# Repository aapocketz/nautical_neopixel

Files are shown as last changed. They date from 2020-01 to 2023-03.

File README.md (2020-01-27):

# Nautical Neopixel Arduino project

This arduino sketch is designed to be programmed into a framed nautical chart in order to light up the buoys, lighthouses, channel markers and other lighted nautical aids to navigation found on a NOAA nautical chart. Each light has a color and flashing/timing characteristic which can be simulated. This would make an interesting art display or a project for someone learning or experimenting with microcontrollers.

See the comments in the sketch for more information on implementation.

You can simulate the operation of the arduino and LEDs on Tinkercad Circuit simulator https://www.tinkercad.com/things/gWAsxpgxWYh.

The chart I printed required over a hundred lighted aids to navigation, some that even printed out in a large format (20x30in) some lateral buoys/marks are spaced closely. I wanted to light them all, so decided to use 1mm fiber optics. This solved the problem with spacing - Neopixels are very small, but even 5050 LEDs are 5mm wide. Since most of the buoys in a given chart will have the same color and timing, you can also multiplex map several fibers fed from a single LED, and even the chart I printed with hundred of lights only required fewer than 20 unique LEDs. By using fewer LEDs and being smarter about power you could also make this project battery powered. 

# SCAD 3D print
To mate the optical fiber to the LEDs, I designed a coupler that makes it easy to mate the fiber to individual LEDs. This SCAD is customizable and can be accessed directly using thingiverse customizer https://www.thingiverse.com/thing:3881790. 

# parts and tools required and project assembly

1. Frame a nautical chart. Find a nautical chart, and a print service and frame style that will work for you. I went with samsclub photo as they have "standout" prints 20x30in for ~$80. Standout prints are a good option as it is a nice hard surface to drill into to mount the LEDs and have a nice deep frame to hide electronics. To print a nautical chart you can get PDF charts for free from NOAA https://nauticalcharts.noaa.gov/. Keep in mind the aspect ratio is varied with each chart, and you will need to either find a print service that can handle custom sizes or crop/trim the image to fit. To match the modern black standout frame and modern look of LEDs I inverted the image which created an image that was darker and I think goes better with the frame and nautical lights against a dark background at night.\
\
For example this is the image I had printed from chart 12270 (warning large image):\
\
Note: I am not sure I would recommend the samsclub standouts, as they have a hard backing and it glued up with styrofoam inside which I didn't realize. To get this project to work I had to cut the backing off and carve out the styrofoam to mount the electronics. It would have been easier with standout frame that had a hollow backing with no solid foam layer. Box mount or canvas mount frames that are hollow in the back may be a better option. 

2. Program the Arduino. I used an Andruino nano board clone from Amazon (a pack of 3 was about $13). https://www.amazon.com/ELEGOO-Arduino-ATmega328P-Without-Compatible/dp/B0713XK923. Figure out the different light sequences you will need for your chart and edit the arduino sketch to include the number of unique LEDs and timing needed.  
*ProTip: Note each nautical light should be clearly printed on the NOAA chart and with a sequence described in chart 1. Also the coast guard provides a list of all the lights in a chart for regions which is a great reference https://www.navcen.uscg.gov/?pageName=lightLists. It helps to put all of them in a spreadsheet and sort by unique to find out how many different unique LEDs you will need. If you have a bunch of the same sequenced lights (ex. flashing green 4s), you may want to have multiple LEDs allocated with them. I wouldn't put more than maybe 10 1mm fibers in a single bundle for each LED (note this is an example of an interesting 2D packing problem https://en.wikipedia.org/wiki/Circle_packing_in_a_circle).*

3. Connect the Arduino to the LED strip to test functionality. I used a cheap ws2812b 144/1M 5050 led strip I found on ebay for ~$12. Trim to the number of LEDs your chart requires. I soldered wire directly to the arduino through holes from the LED strip to finalize the attachment.

4. 3D print the coupler from thingiverse. The LED strip should mount easily in the assembly with channels for optical fiber to each LED. Figure out where you will mount the LEDs behind your frame.

5. Drill holes for each fiber optic to poke through the print. I used a 1mm drill bit attached to a dremel. If you don't have a dremel you could use a small hand drill like a pin vise, which are very cheap. 

6. Mount the optical fiber. Push the fiber through each hole in the print, trimming the end with a flush cutter/wire cutter. To prevent the end from pulling through the print and to spread the light a bit, tap the end of the soldering iron to the end of the fiber, the plastic will mushroom out a bit preventing it from pulling through. Make sure you leave enough fiber length to reach the place where you are mounting the LEDs in the frame.
50m of 1mm fiber optics is about $8 on amazon https://smile.amazon.com/gp/product/B07W979RH3/. 

7. route the fiber optics to the LEDs and attach them to the coupler. I recommend only mounting fiber and routing for a single LED color at a time, so for instance all Flashing Red 2.5s should be pushed through and attached before going on to the next color/timing. To attach to the coupler I recommend clear gorilla glue ($8 for a large bottle https://smile.amazon.com/Gorilla-Clear-Glue-ounce-Bottle/dp/B074J7XQZT) as it dries really clear to not block light. I don't recommend hot glue as you can easily melt the fiber optics! The only downside of the Gorilla glue is it takes time to set, so I recommend gluing up one LED at a time and letting it set before working on the next LED.

8. Mount the power cable. I powered the Arduino using a USB panel mount connector. USB cables are cheap and it allows the program to be reprogrammable after framing. You could also power the project with a barrel connector and a cheap 5v supply, or even use batteries. USB type B to USB mini panel mount connector is about $9 https://www.amazon.com/gp/product/B07PJYNTKS/. Note the panel mount I ordered didn't come with screws, but I had some spare screws that worked (I think size M3).

9. Cover the backing. This is optional, but with loose fiber everywhere it helps encapsulate everything. I glued a black plastic corregated board to the back ($4 at https://www.michaels.com/plastic-corrugated-board-by-creatology/M10567770.html).

## results

video of chart LEDs flashing: https://youtu.be/PLgCkBzhD6o  
video of 3D printed LED coupler: https://www.youtube.com/watch?v=q0YkyLGdePY

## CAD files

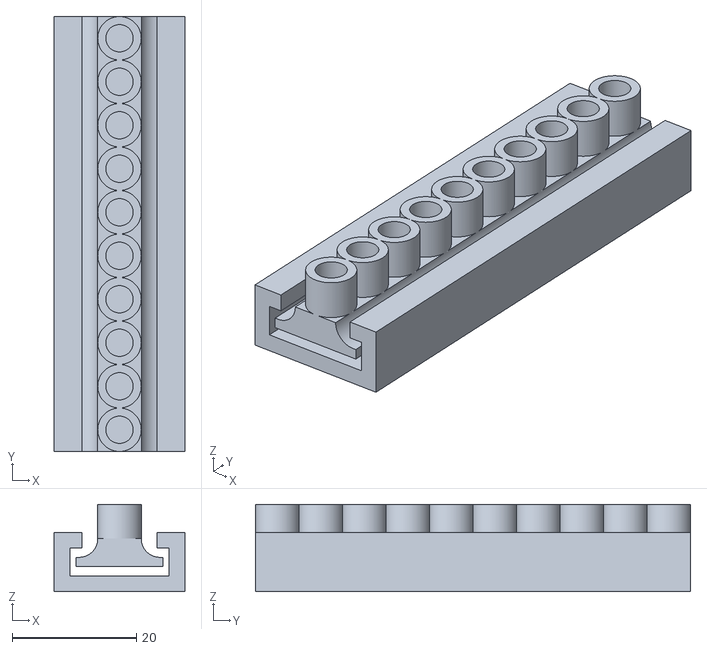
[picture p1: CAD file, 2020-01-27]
neopixel_fiber_adapter.stl
21.0 x 70.0 x 14.0

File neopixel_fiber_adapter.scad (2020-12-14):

/* [Global] */

// Which one would you like to see?
part = "both"; // [top:Top Only,base:Base Only,both:Top and Base]

/* [Top] */

// number of holes for LEDs
led_count = 10;
// length of the tube for fiber optics
tube_height = 10;
// width of the base (wings at bottom)
width = 14.0;
// radius of the chamfer to the wings. Larger number is more gradual chamfer.
chamfer_radius = 3.0;
// radius of the fillet of the base. This is mainly there to make it easier to print
fillet_radius = 1.0;
// the height fo the base (wings) on the side. Chamfer radius + wing height must be less than the tube_height
wing_height = 1.5;

// LED size (ws2812b according to datasheet is 5.0 * 5.4 * 1.57 with a 0.05mm tolerance.)
led_size = [5.4, 5.6, 1.65];

/* [Base] */

// thickness of the wall for the base
wall_thickness = 2.5;

// base clearance factor for clearance issues on the base
clearance = 1.1;
// led strip thickness
strip_thickness = 1.1;

/* [Hidden] */
$fn=100;

print_part();

module print_part() {
    if (part == "top") {
        led_top();
    } else if (part == "base") {
        led_base();
    } else {
        led_top();
        led_base();
    }
}


module led_top() {
    for (i=[0:led_count-1]) {
        translate([0, 7 * i, 0]) {
            difference() {
                union() {
                    // wing and chamfer material
                    translate([0, 0, (chamfer_radius + wing_height)/2]){
                        cube([width, 7, chamfer_radius + wing_height], true);
                    }
                    // tube material
                    translate([0, 0, tube_height/2]) {
                        cylinder(tube_height, 3.5, 3.5, true);
                    }
                }

                // chamfer each side
                for (side = [-1,1]) {
                    translate([side * (chamfer_radius + 3.5), 0, chamfer_radius + wing_height]) {
                        rotate([0, 90, 90]) {
                            cylinder(8, chamfer_radius, chamfer_radius, true);
                        }
                    }
                    translate([side * (width/2 + chamfer_radius + 3.5), 0, chamfer_radius + wing_height]) {
                        cube([width, 8, chamfer_radius*2], true);
                    }
                }

                // LED slot
                translate([0, 0, led_size[2]/2 - 0.01]) {
                    cube(led_size, true);
                }

                // Fiber tube
                cylinder(tube_height * 3, 2.2, 2.2, true);
            }
        }
    }
}

module led_base() {
    slot_depth = strip_thickness + wing_height;
    translate([0, 0, wing_height/2]) {
        for (i=[0:led_count-1]) {
            translate([0, 7 * i, 0]) {
                difference() {
                    // the overall base
                    cube([width + wall_thickness*2 + clearance*2, 7, slot_depth + wall_thickness*2 + clearance*2], true);
                    difference(){
                        // main LED slot in base
                        cube([width + clearance*2, 8, slot_depth + clearance*2], true);
                        // subtract out the fillet area
                        union() {
                            translate([width/2 + clearance, 0, slot_depth/2 + clearance]) {
                                difference(){
                                    translate([-fillet_radius/2, 0, -fillet_radius/2]){
                                        cube([fillet_radius, 8, fillet_radius], true);
                                    }
                                    translate([-fillet_radius, 0, -fillet_radius]){
                                        rotate([0, 90, 90]) {
                                            cylinder(9, fillet_radius, fillet_radius, true);
                                        }
                                    }
                                }
                            }
                            translate([-(width/2 + clearance), 0, slot_depth/2 + clearance]) {
                                difference(){
                                    translate([fillet_radius/2, 0, -fillet_radius/2]){
                                        cube([fillet_radius, 8, fillet_radius], true);
                                    }
                                    translate([fillet_radius, 0, -fillet_radius]){
                                        rotate([0, 90, 90]) {
                                            cylinder(9, fillet_radius, fillet_radius, true);
                                        }
                                    }
                                }
                            }
                        }
                    }
                    // the opening at the top of the base
                    translate([0, 0, (slot_depth + wall_thickness)/2 + clearance]) {
                       cube([width - clearance*2, 8, wall_thickness + 0.01], true);
                    }
                }
            }
        }
    }
}

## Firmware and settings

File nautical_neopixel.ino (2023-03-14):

// nautical light display using neopixels
// author: Aaron Paquette <aapocketz@gmail.com

// NEOPIXEL BEST PRACTICES for most reliable operation:
// - Add 1000 uF CAPACITOR between NeoPixel strip's + and - connections.
// - MINIMIZE WIRING LENGTH between microcontroller board and first pixel.
// - NeoPixel strip's DATA-IN should pass through a 300-500 OHM RESISTOR.
// - AVOID connecting NeoPixels on a LIVE CIRCUIT. If you must, ALWAYS
//   connect GROUND (-) first, then +, then data.
// - When using a 3.3V microcontroller with a 5V-powered NeoPixel strip,
//   a LOGIC-LEVEL CONVERTER on the data line is STRONGLY RECOMMENDED.
// (Skipping these may work OK on your workbench but can fail in the field)

#include <Adafruit_NeoPixel.h>
#ifdef __AVR__
#include <avr/power.h> // Required for 16 MHz Adafruit Trinket
#endif

// how many LEDs are we using for navigation lights
#define LED_COUNT 20

// Which pin on the Arduino is connected to the NeoPixels?
// On a Trinket or Gemma we suggest changing this to 1:
#define LED_PIN 6

// clang-format off
// array of char strings
// these must correspond to NOAA nautical chart 1 specifications for
// lighted aids to navigation, indicating the pattern and color of lights
// as listed on nautical charts themselves
// for example "Fl R 4s" would be Flashing Red 4 second period"
// or "Fl (4+5) G 30s" would be 4 green short flashes followed by
// 5 green short flashes every 30 seconds
// NOTE: there are a lot of options for lighted aids, and handlers may
// need to be added for types not included here!
// a good reference is this:
// https://www.navcen.uscg.gov/pdf/lightlists/LightList_V2_2019.pdf

// these are the nautical lights needed for chart 12270
// Chesapeake Bay Eastern Bay and South River; Selby Bay
// https://www.charts.noaa.gov/OnLineViewer/12270.shtml
// char* nav_leds[LED_COUNT] = {
//   "Fl (4+5) G 30s",
//   "Fl G 4s",
//   "Q G",
//   "Fl G 2.5s",
//   "Fl (2+1) G 6s",
//   "Fl G 6s",
//   "Q R",
//   "Fl R 2.5",
//   "Fl R 4s",
//   "Fl R 6s",
//   "Fl (2+1) R 6s",
//   "Fl W 6s",
//   "Fl W 10s",
//   "Fl W 4s",
//   "Fl W 5s",
//   "Fl (4+3) Y 30s",
//   "Fl Y 2.5s",
//   "Fl Y 4s",
//   "F Y",
//   "Oc (2+1) R 6s"
// };


// nautical chart 12283 Annapolis Harbor
// https://www.charts.noaa.gov/OnLineViewer/12283.shtml
char* nav_leds[LED_COUNT] = {
  "Q W",
  "Q G",
  // "F M",
  "Fl (4+5) G 30s",
  // "F M",
  "Fl (4+3) Y 30s",
  // "F M",
  "Fl R 2.5s",
  "Fl Y 2.5s",
  "Fl G 2.5s",
  // "F M",
  "Fl R 4s",
  "Fl Y 4s",
  // "F M",
  "Fl R 6s",
  "Fl W 6s",
  // "F M",
  "Fl W 10s"
};


// // test examples
// char* nav_leds[LED_COUNT] = {
//   "Q (6+LFl) R 15s",
//   "L.Fl G 10s",
//   "Q R",
//   "VQ R",
//   "UQ R",
//   "VQ (3) G 5s",
//   "Mo (U) R 6s",
//   "Iso R 5s",
//   "Q G",
//   "Q (2) R 10s",
//   "Q (2+1) G 10s",
//   "Fl R 10s",
//   "Oc G 10s"

// };
// clang-format on

// ms between simulated ticks.
#define TICK_PERIOD 100

// flash duration (period light is on during flashing (or off for occulting)
// duty cycle for normal flash will be FLASH_DURATION/FLASH_PERIOD
// flashing period (flash 30 times a minute)
#define FLASH_DURATION 500
#define FLASH_PERIOD 2000

// quick flashing duration/period (flash 60 times a minute)
#define QUICK_DURATION 500
#define QUICK_PERIOD 1000

// very quick flashing period (flash 120 times a minute)
#define VERY_QUICK_DURATION 250
#define VERY_QUICK_PERIOD 500

// ultra quick flashing period (flash 240 times a minute)
#define ULTRA_QUICK_DURATION 125
#define ULTRA_QUICK_PERIOD 250

// long flashing period (flash 30 times a minute)
#define LONG_FLASH_DURATION 2000
#define LONG_FLASH_PERIOD 4000

// morse code constants
char *alpha[] = {
    ".-",   // A
    "-...", // B
    "-.-.", // C
    "-..",  // D
    ".",    // E
    "..-.", // F
    "--.",  // G
    "....", // H
    "..",   // I
    ".---", // J
    "-.-",  // K
    ".-..", // L
    "--",   // M
    "-.",   // N
    "---",  // O
    ".--.", // P
    "--.-", // Q
    ".-.",  // R
    "...",  // S
    "-",    // T
    "..-",  // U
    "...-", // V
    ".--",  // W
    "-..-", // X
    "-.--", // Y
    "--.."  // Z
};

#define MORSE_UNIT 500
#define DOT_TIME 1 * MORSE_UNIT
#define DASH_TIME 3 * MORSE_UNIT
#define SPACE_TIME 1 * MORSE_UNIT

// shift the phase so the leds are less likely to blink at the same time
// lowering the max current draw
// each LED will start its period shifted by phase offset. Set to zero if
// you want them blinking simultaneously
int phase_offset = FLASH_DURATION * 0;

// Declare our NeoPixel strip object:
Adafruit_NeoPixel strip(LED_COUNT, LED_PIN, NEO_GRB + NEO_KHZ800);
// Argument 1 = Number of pixels in NeoPixel strip
// Argument 2 = Arduino pin number (most are valid)
// Argument 3 = Pixel type flags, add together as needed:
//   NEO_KHZ800  800 KHz bitstream (most NeoPixel products w/WS2812 LEDs)
//   NEO_KHZ400  400 KHz (classic 'v1' (not v2) FLORA pixels, WS2811 drivers)
//   NEO_GRB     Pixels are wired for GRB bitstream (most NeoPixel products)
//   NEO_RGB     Pixels are wired for RGB bitstream (v1 FLORA pixels, not v2)
//   NEO_RGBW    Pixels are wired for RGBW bitstream (NeoPixel RGBW products)

// commonly used nautical light colors
const uint32_t RED = strip.Color(255, 0, 0);
const uint32_t GREEN = strip.Color(0, 255, 0);
const uint32_t YELLOW = strip.Color(255, 255, 0);
const uint32_t WHITE = strip.Color(127, 127, 127);
// const uint32_t WHITE = strip.Color(0, 0, 255); // use blue for testing as its
// more visible than white
const uint32_t MAGENTA = strip.Color(255, 0, 255);
const uint32_t OFF = strip.Color(0, 0, 0);

unsigned int global_counter = 0;

// setup() function -- runs once at startup --------------------------------

void setup() {
  // These lines are specifically to support the Adafruit Trinket 5V 16 MHz.
  // Any other board, you can remove this part (but no harm leaving it):
#if defined(__AVR_ATtiny85__) && (F_CPU == 16000000)
  clock_prescale_set(clock_div_1);
#endif
  // END of Trinket-specific code.

  Serial.begin(9600); // Init serial monitor for debugging

  strip.begin(); // INITIALIZE NeoPixel strip object (REQUIRED)
  strip.show();  // Turn OFF all pixels ASAP
  // strip.setBrightness(50); // Set BRIGHTNESS to about 1/5 (max = 255)
}

// loop() function -- runs repeatedly as long as board is on ---------------

void loop() {
  strip.clear();
  unsigned int counter = global_counter;
  for (int led_idx = 0; led_idx < LED_COUNT; ++led_idx) {
    parse(counter, led_idx, nav_leds[led_idx]);
    counter += phase_offset;
  }
  strip.show();       // Update strip with new contents
  delay(TICK_PERIOD); // increment tick
  global_counter += TICK_PERIOD;
}

// utility function color mapping
uint32_t charToColor(char ch) {
  switch (ch) {
  case 'R':
    return RED;
  case 'G':
    return GREEN;
  case 'Y':
    return YELLOW;
  case 'W':
    return WHITE;
  default:
    // magenta may indicate error!
    return MAGENTA;
  }
}

// utility function period parsing
int aToPeriod(char *cstr) {
  int len = strlen(cstr);
  if (len > 0 and cstr[len - 1] == 's') {
    // lop off s in string
    cstr[len - 1] = NULL;
  }
  float seconds = atof(cstr);
  return seconds * 1000;
}

// parse the lighting characteristics string
void parse(unsigned int count, int led_idx, char *str) {
  // main color
  uint32_t color = MAGENTA;

  // check the length string
  int len = strlen(str);

  // ensure the length is something reasonable
  if (len < 2 or len > 30)
    return;

  if (str[0] == 'I' and str[1] == 's' and str[2] == 'o') {
    // isophase
    color = charToColor(str[4]);
    int period = aToPeriod(&str[6]);
    flash(count, led_idx, color, OFF, 1, 0, period / 2, 0, period);
  } else if (str[0] == 'Q') {
    if (str[1] == ' ' and str[2] != '(') {
      // quick flashing
      color = charToColor(str[2]);
      flash(count, led_idx, color, OFF, 1, 0, QUICK_DURATION,
            QUICK_PERIOD - QUICK_DURATION, QUICK_PERIOD);
    } else {
      // quick group flashing
      // very quick group flashing
      int group1 = 1;
      int group2 = 0;
      int period = 100000;
      str += 2;
      int char_skip = aToGroups(str, group1, group2);
      str += char_skip;
      color = charToColor(str[0]);
      period = aToPeriod(&str[2]);
      flash(count, led_idx, color, OFF, group1, group2, QUICK_DURATION,
            QUICK_PERIOD - QUICK_DURATION, period);
    }
  } else if (str[0] == 'V' and str[1] == 'Q') {
    // very quick
    if (str[2] == ' ' and str[3] != '(') {
      // very quick flashing
      color = charToColor(str[3]);
      flash(count, led_idx, color, OFF, 1, 0, VERY_QUICK_DURATION,
            VERY_QUICK_PERIOD - VERY_QUICK_DURATION, VERY_QUICK_PERIOD);
    } else {
      // very quick group flashing
      int group1 = 1;
      int group2 = 0;
      int period = 100000;
      str += 3;
      int char_skip = aToGroups(str, group1, group2);
      str += char_skip;
      color = charToColor(str[0]);
      period = aToPeriod(&str[2]);
      flash(count, led_idx, color, OFF, group1, group2, VERY_QUICK_DURATION,
            VERY_QUICK_PERIOD - VERY_QUICK_DURATION, period);
    }
  } else if (str[0] == 'U' and str[1] == 'Q') {
    // ultra quick
    if (str[2] == ' ' and str[3] != '(') {
      // ultra quick flashing
      color = charToColor(str[3]);
      flash(count, led_idx, color, OFF, 1, 0, ULTRA_QUICK_DURATION,
            ULTRA_QUICK_PERIOD - ULTRA_QUICK_DURATION, ULTRA_QUICK_PERIOD);
    } else {
      // ultra quick group flashing
      int group1 = 1;
      int group2 = 0;
      int period = 100000;
      str += 3;
      int char_skip = aToGroups(str, group1, group2);
      str += char_skip;
      color = charToColor(str[0]);
      period = aToPeriod(&str[2]);
      flash(count, led_idx, color, OFF, group1, group2, ULTRA_QUICK_DURATION,
            ULTRA_QUICK_PERIOD - ULTRA_QUICK_DURATION, period);
    }
  } else if (str[0] == 'F') {
    if (str[1] == ' ') {
      // fixed color
      color = charToColor(str[2]);
      fixed(count, led_idx, color);
    } else if (str[1] == 'l' and str[2] == ' ') {
      // flashing
      int group1 = 1;
      int group2 = 0;
      int period = 100000;
      str += 3;
      int char_skip = aToGroups(str, group1, group2);
      str += char_skip;
      color = charToColor(str[0]);
      period = aToPeriod(&str[2]);
      flash(count, led_idx, color, OFF, group1, group2, FLASH_DURATION,
            FLASH_PERIOD - FLASH_DURATION, period);
    }
  } else if (str[0] == 'L' and str[1] == '.' and str[2] == 'F' and
             str[3] == 'l') {
    // flashing
    int group1 = 1;
    int group2 = 0;
    int period = 100000;
    str += 5;
    int char_skip = aToGroups(str, group1, group2);
    str += char_skip;
    color = charToColor(str[0]);
    period = aToPeriod(&str[2]);
    flash(count, led_idx, color, OFF, group1, group2, LONG_FLASH_DURATION,
          LONG_FLASH_PERIOD - LONG_FLASH_DURATION, period);
  } else if (str[0] == 'O' and str[1] == 'c') {
    // occulting
    // flashing
    int group1 = 1;
    int group2 = 0;
    int period = 100000;
    str += 3;
    int char_skip = aToGroups(str, group1, group2);
    str += char_skip;
    color = charToColor(str[0]);
    period = aToPeriod(&str[2]);
    flash(count, led_idx, OFF, color, group1, group2, FLASH_DURATION,
          FLASH_PERIOD - FLASH_DURATION, period);
  } else if (str[0] == 'M' and str[1] == 'o') {
    // Morse code
    if (str[3] == '(' and str[5] == ')') {
      char ch = str[4];
      // offset pointer
      str += 7;
      color = charToColor(str[0]);
      int period = aToPeriod(&str[2]);
      morse(count, led_idx, color, ch, period);
    }
  }
}
// determine groups from strings
// return: number of char consumed
// group1 and group2 are also return values
int aToGroups(char *str, int &group1, int &group2) {
  if (str[0] == '(' and isdigit(str[1])) {
    if (str[2] == ')') {
      // single group flashing
      group1 = atoi(&str[1]);
      group2 = 0;
      return 4;
    } else if (str[2] == '+' and isdigit(str[3]) and str[4] == ')') {
      // composite group flashing
      group1 = atoi(&str[1]);
      group2 = atoi(&str[3]);
      return 6;
    } else if (str[2] == '+' and str[3] == 'L' and str[4] == 'F' and
               str[5] == 'l' and str[6] == ')') {
      // composite group flashing with second group long flash
      group1 = atoi(&str[1]);
      group2 = -1; // use negative values to support long flashes
      return 8;
    }
  } else {
    group1 = 1;
    group2 = 0;
    return 0;
  }
}

// fixed color
void fixed(unsigned int count, int led_idx, uint32_t color) {
  strip.setPixelColor(led_idx, color);
}

// clang-format off
// flashing
// controls sequence of led flashes
//
// count: the clock counter in microsec ticks
//
// led_idx: the led index
//
// on_color: the color of the led when the flash is "on". Note: occulting lights
// this color could be "OFF" off_color: the color of the led when the flash is
// "off". Normal lights will have this color be "OFF"
//
// group1: the number of flashes during the first half period
//
// group2: number of flashes during the second half period
//
// on_time: the number of ticks the light is "on" when flashing
//
// off_time: the number of ticks the light is "off" when flashing
//
// period: the repeat period of the flashes
//
// example:
// this is what a group1=2, group2=0, on_time=5, off_time=5, and period of 40
// would look like the | represents the period, the {} are groups and the + is
// when we are on, and the - are when we are off.
//
//             |{+++++-----+++++-----}{--------------------}|
//
// important note! this function currently doesn't do any error checking to make
// sure values are sane.
// clang-format on

void flash(unsigned int count, int led_idx, uint32_t on_color,
           uint32_t off_color, int group1, int group2, int on_time,
           int off_time, int period) {
  count = count % period;
  uint32_t active_color = off_color;

  int sub_period = on_time + off_time;

  int subframe = count / sub_period;
  // determine groupset
  // assume half the period is for the first grouping
  int group = group1;
  if ((count * 2) >= period) {
    group = group2;
    if (group < 0) {
      // special case long flash, kinda hacky here
      // modify the flash duration values
      group = -group;
      on_time = LONG_FLASH_DURATION;
      off_time = LONG_FLASH_PERIOD - LONG_FLASH_DURATION;
      sub_period = on_time + off_time;
    }
    count = count % (period / 2);
    subframe = count / sub_period;
  }
  if (subframe < group) {
    active_color = on_color;
  }
  if ((count % sub_period) > on_time) {
    active_color = off_color;
  }

  strip.setPixelColor(led_idx, active_color);
}

void morse(unsigned int count, int led_idx, uint32_t color, char ch,
           int period) {
  count = count % period;
  char *code_str = alpha[ch - 'A'];

  uint32_t active_color = OFF;
  int on_time = 0;
  for (int i = 0; i < strlen(code_str); ++i) {
    char t = code_str[i];
    int off_time = on_time;
    if (t == '.') {
      off_time += DOT_TIME;
    } else {
      off_time += DASH_TIME;
    }
    if (on_time <= count and count < off_time) {
      active_color = color;
      break;
    }
    on_time = off_time + SPACE_TIME;
  }
  strip.setPixelColor(led_idx, active_color);
}

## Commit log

2020-01-27 initial add arduino sketch source code
2020-01-27 adding openscad LED fiber optic coupler
    * still need to 3D print and test
    [neopixel_fiber_adapter.scad]
2020-01-27 improving scad
    * adding more clearance on base for led strip
    * adding the size of the led to parameters
    [neopixel_fiber_adapter.scad, neopixel_fiber_adapter.stl]
2020-01-27 adding occulting lights to arduino code
2020-01-27 more readme and BOM info. added inverted chart jpg.
2020-12-14 Update neopixel_fiber_adapter.scad
    added fillet area to the base for better printing. Fixing some parameters so they show up as float in customizer.
    [neopixel_fiber_adapter.scad]
2023-03-19 changing to platformio project from arduino
2023-04-02 ability to set individual phase per led
    allows isolating colors
